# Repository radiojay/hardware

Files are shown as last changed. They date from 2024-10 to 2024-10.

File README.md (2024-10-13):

RadioJay Hardware Design
========================

This repo has various hardware designs for RadioJay wildlife tracking tags.
The first few were called "Mostag" for "Motus Open Source TAG" and then later rebranded to RadioJay.
The tags are listed here more or less in reverse chronological order.

For write-ups about these tags see the [RadioJay](https://radiojay.org) web site.

### RadioJay G1 - LoRaWAN+GPS tag

This is a collection of test & dev boards using a bit more space and with connectors to
attach probes and to swap between solar panels and GPS modules.

- [RadioJayG1-ublox](./RadioJayG1-ublox/) has a U-Blox Mia-M10Q GPS and an stm32wle5
  microcontroller with integrated LoRa radio.
- [RadioJayG1-lr1110](./RadioJayG1-lr1110/) has an LR1110 radio with snapshot GPS and with LoRa
  support and uses an stm32u083 microcontroller.
- [RadioJayG1-aem](./RadioJayG1-aem/) is a solar + battery module using an e-Peas AEM10330 energy
  harvesting chip with integrated buck converter; it can be used with a PowerFilm or an IXOLAR
  solar cell and with a LiPO or an LTO battery.
- [RadioJayG1-lr1110](./RadioJayG1-lr1110/) is a solar/battery module using an IXOLAR solar cell
  with an MPP volatge of 4.4V allowing direct charge without boost converter; it has a low Iq
  buck converter to output 1.8V

### RadioJay A2 / MostagV2

First real tag using FlexPCB with a target weight of 1g all-in (incl. loop harness).
Uses uC, Nichicon battery, PowerFilm solar, bq25504, and accelerometer
as well as altimeter (barometer)

RadioJay A2

#### RadioJay A2a / MostagV2a

Same board with layout changes to satisfy OSH Park's design rules.

### PgmAdapterV2

Adapter board for programming RadioJay A2MostagV2 using a simple USB-serial adapter chip.
Has connectors to attach various types of programming/debug probes.
Most likely not what "normal users" will use, but useful for development.

PgmAdapterV2

### RadioJay A1 / MostagV1

Initial proof of concept board, not for strapping to any animal, has uC,
Seiko battery, PowerFilm solar cell, bq25504, and accelerometer, plus linx antenna.

RadioJay A1

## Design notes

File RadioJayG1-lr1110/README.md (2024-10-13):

RadioJay G1 - LR1110
====================

Test & dev board for a Semtech LR1110, providing GPS snapshot functionality as well as LoRa radio.
A STM32U083 is used as microcontroller for its low power features, familiarity with its peripherals,
and its 256KB flash, which can be used to store GPS data.

The main purpose of the board is to prototype all the pieces and be able to measure power consumption.

Open questions that came up while designing the board:
- Is it possible to get away without 900Mhz RF switch, as one can with the stm32wle?
  The stm32wle datasheet has a footnote in the "sub-Ghz radio characteristics" stating
  "When not in RX operation mode up to 22 dBm is accepted [on RFI_P/RFI_N]". Neither the
  sx1262 nor the lr1110 datasheet have this note so it's not clear whether this is a feature added
  by ST when integrating the sx1262 or whether it's something Semtech doesn't feel the need to specify.
- Can the GPS LNA power be supplied by the LR1110, eliminating one awkward to route signal. The
  datasheet doesn't specify max source current but it does spec minimum V-high voltage @2.5mA,
  which is the typ consumption of the LNA (max is 3.5mA).
- What are the power consumption implications of having only one 32.768kHz xtal and routing the
  clock from the stm32u083 to the LR1110?
- Would rotating the stm32u883 improve the routing?
- What are the minimum RF test points needed in the "final" tag?

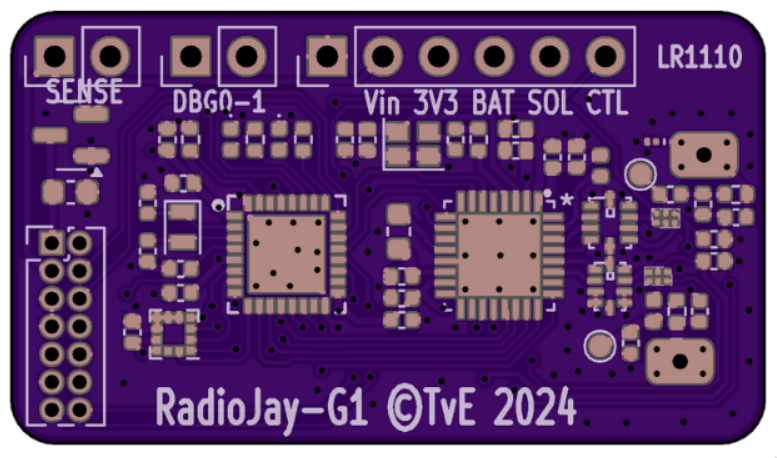
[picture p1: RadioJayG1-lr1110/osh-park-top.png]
Osh park board image


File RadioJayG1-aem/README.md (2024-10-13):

RadioJay G1
===========

Solar / battery module using a low-voltage solar cell (either IXOLAR or PowerFilm) with
E-Peas AEM10330 energy harvesting chip which has a buck converter to output 1.8V.

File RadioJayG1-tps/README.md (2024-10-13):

RadioJay G1
===========

Solar power test board using a solar panel with a MPP voltage around 4.4V allowing direct
charge of a LiPO battery without boost charger.
A high side power switch is used to end the charge and a switching power supply with extremely 
low Iq is used to output 1.8V.

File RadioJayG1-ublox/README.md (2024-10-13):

RadioJay G1
===========

Test & dev board for U-Blox Mia10Q GPS with stm32wle5 microcontroller and integrated LoRa radio.
This board needs to be powered at 1.8V due to the Mia-M10Q
(which could alternatively be powered at 3.3V).

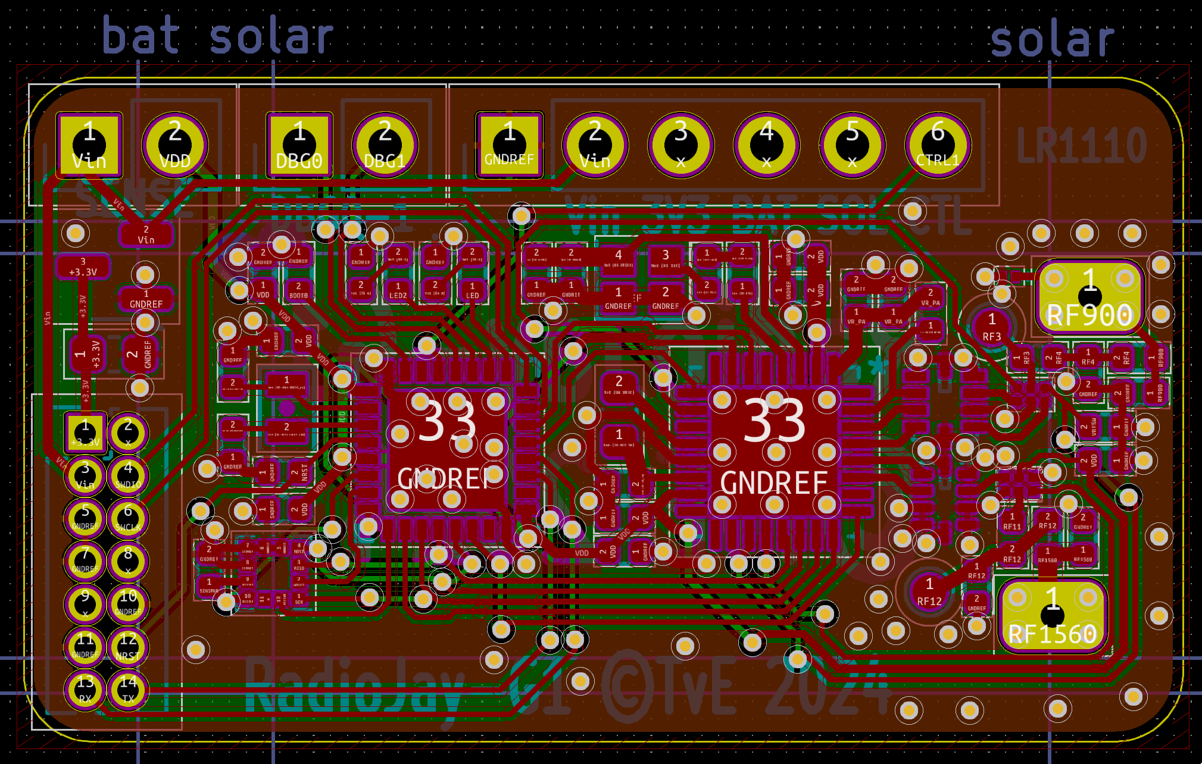
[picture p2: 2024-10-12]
RadioJayG1-lr1110/RadioJayG1-lr1110-pcb-front.png

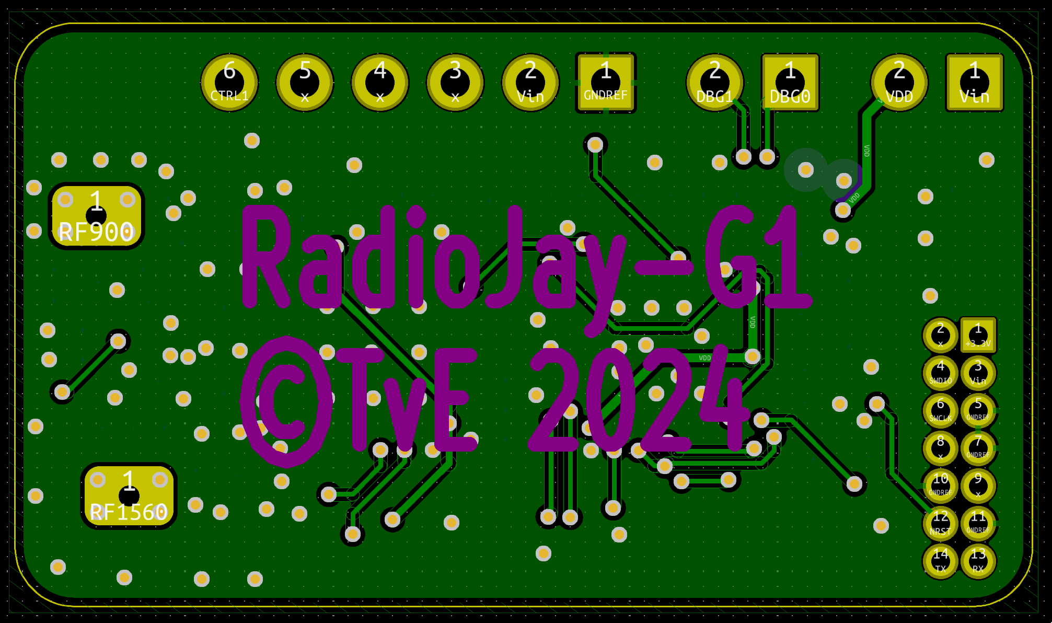
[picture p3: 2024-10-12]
RadioJayG1-lr1110/RadioJayG1-lr1110-pcb-back.png

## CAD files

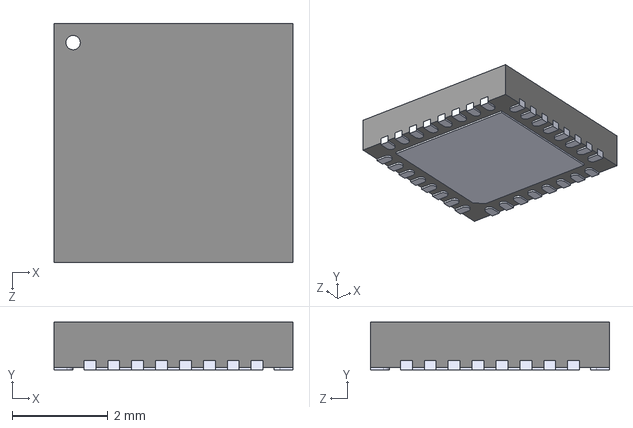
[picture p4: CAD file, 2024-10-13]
3d-models/LR1110IMLTRT.step
5.00 x 1.00 x 5.00 mm

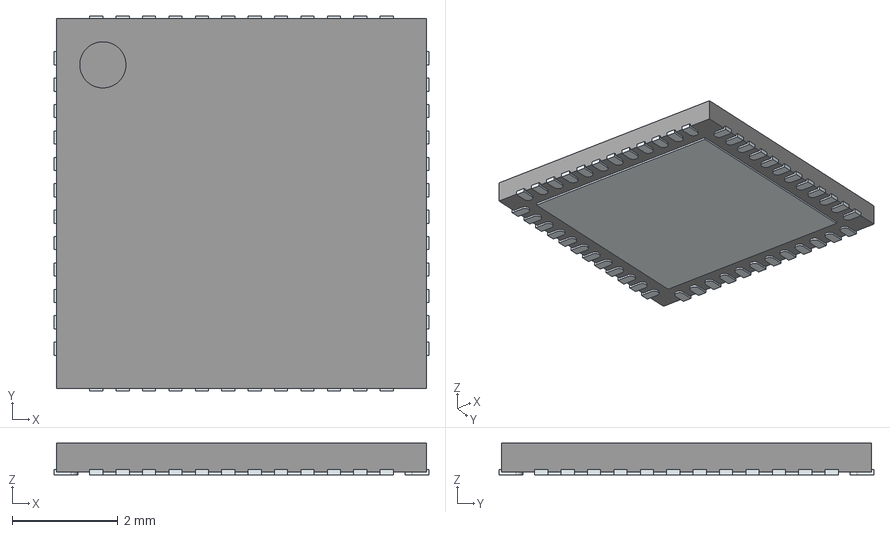
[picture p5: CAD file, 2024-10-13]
3d-models/STM32U083CCU6.stp
7.10 x 7.10 x 0.6 mm
ThermalPin
PinsArrayLR
PinsArrayTB

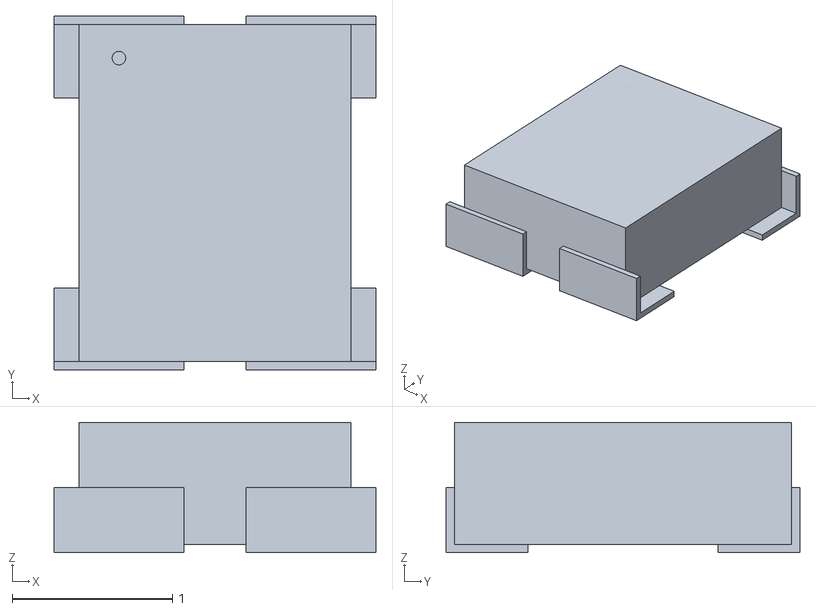
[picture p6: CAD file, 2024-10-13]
3d-models/NT2016SA-32M-END4263A_NDK.stl
2.01 x 2.21 x 0.815

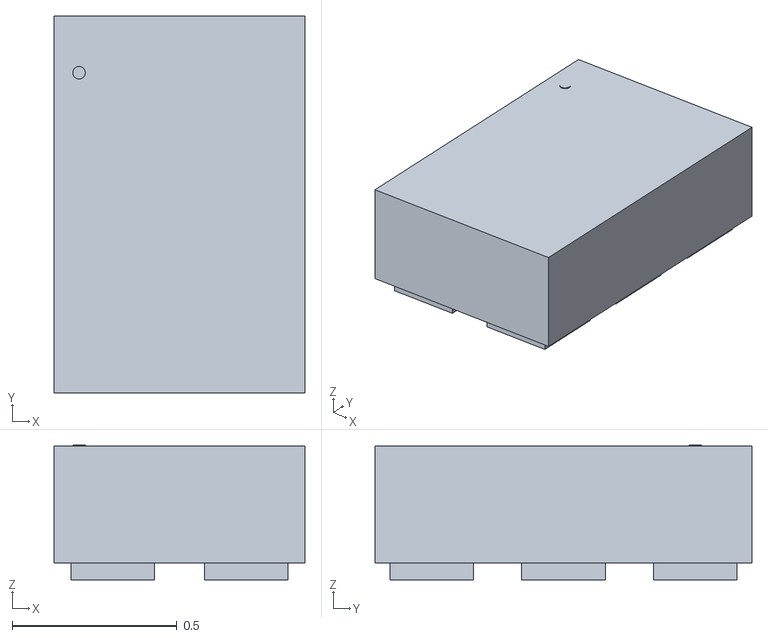
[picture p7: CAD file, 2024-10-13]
3d-models/PG-TSNP-6-2_INF.stl
0.762 x 1.14 x 0.409

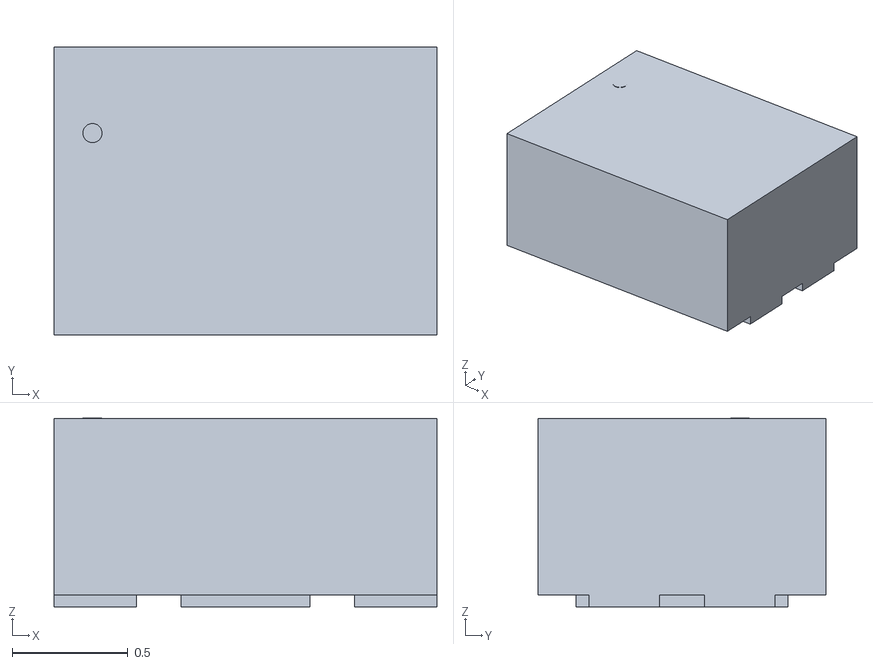
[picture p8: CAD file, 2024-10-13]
3d-models/DFN_NP3-T1GE4_VIS.stl
1.65 x 1.24 x 0.815

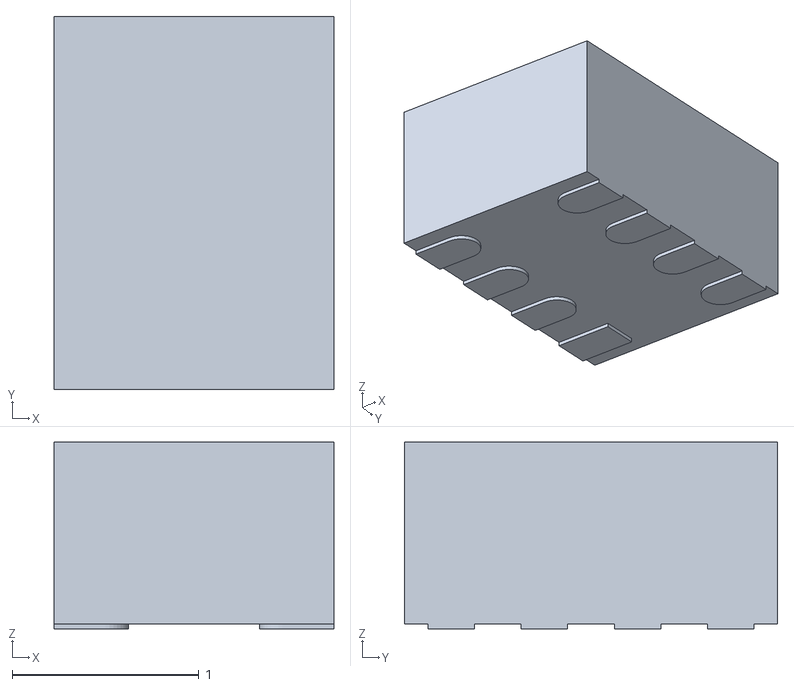
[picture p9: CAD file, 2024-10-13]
3d-models/DLC0008B.stl
1.50 x 2.00 x 1.00

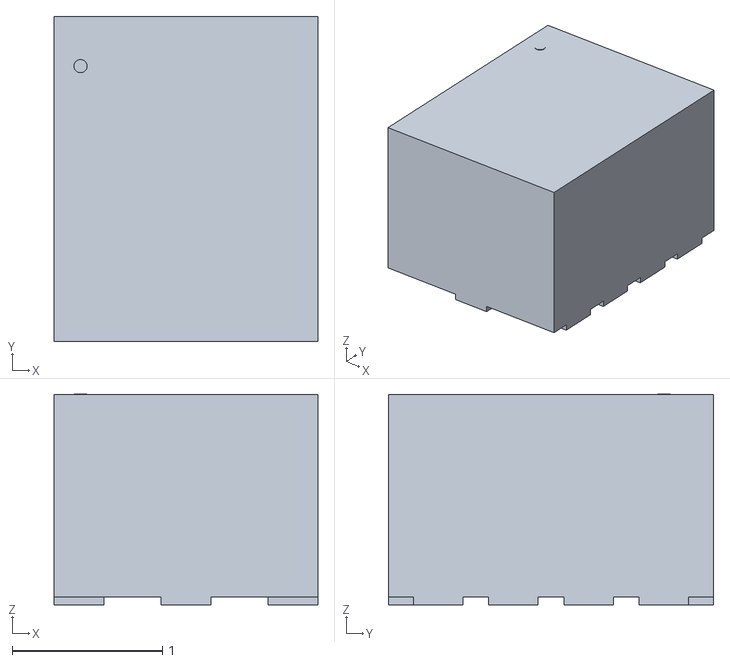
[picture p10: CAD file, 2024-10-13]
3d-models/CM80715_JOT.stl
1.75 x 2.16 x 1.40

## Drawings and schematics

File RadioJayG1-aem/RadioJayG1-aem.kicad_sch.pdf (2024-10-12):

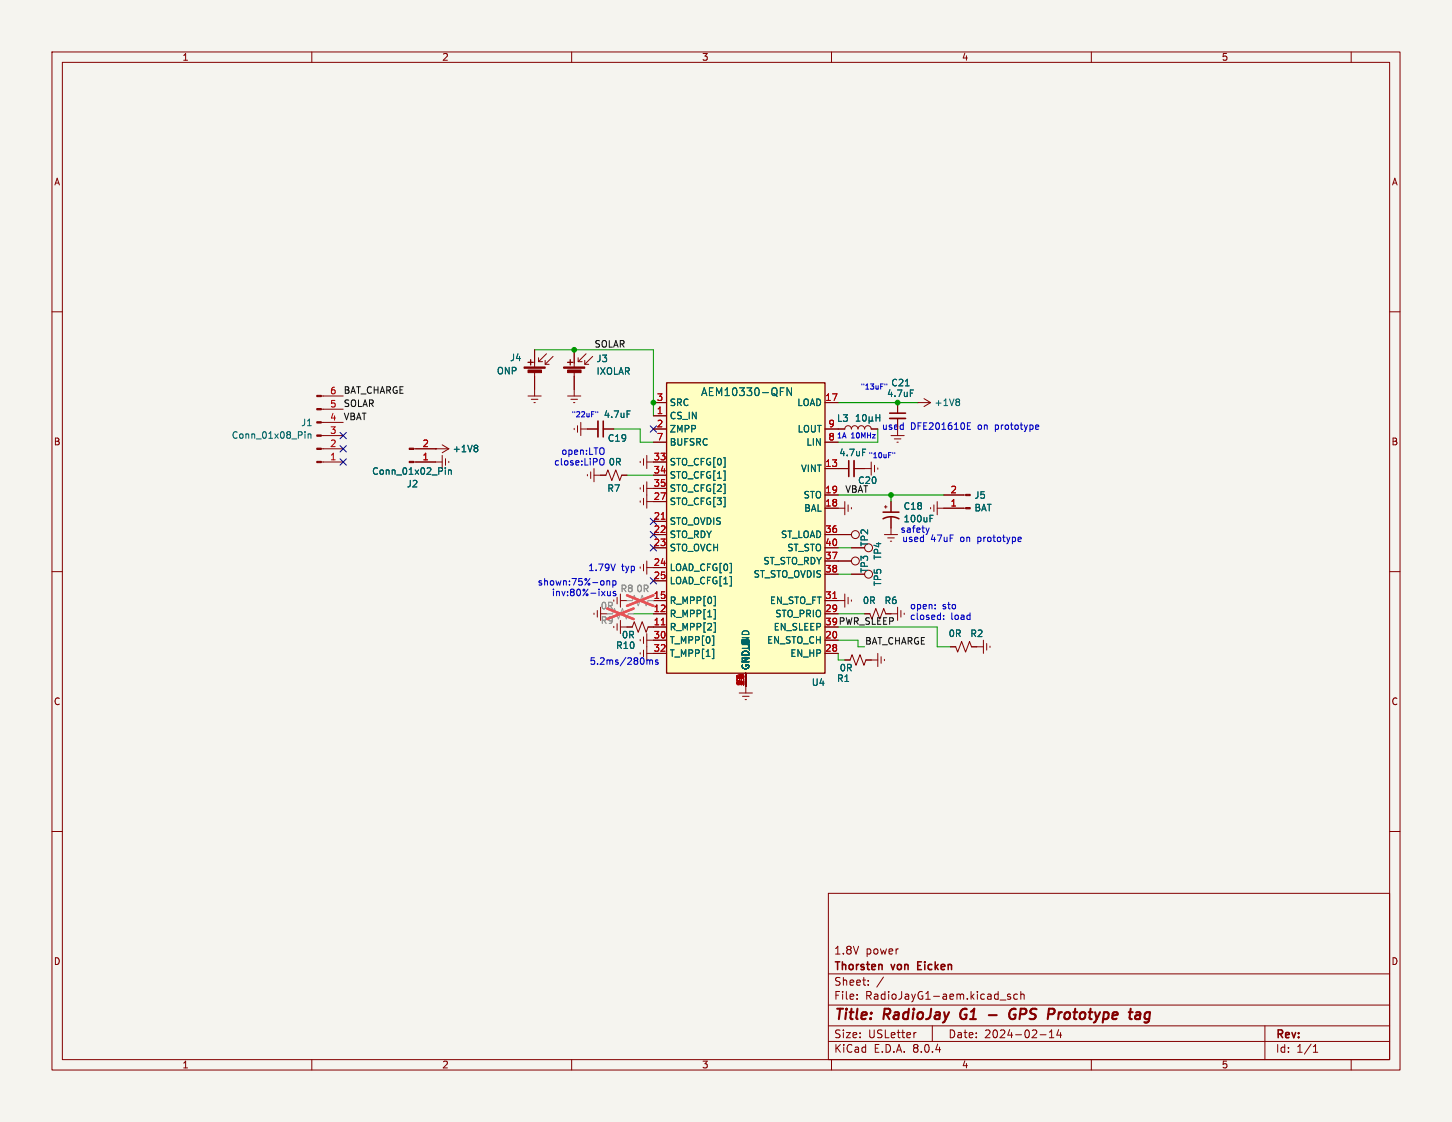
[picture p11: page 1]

Id: 1/1 Title: RadioJay G1 - GPS Prototype tag

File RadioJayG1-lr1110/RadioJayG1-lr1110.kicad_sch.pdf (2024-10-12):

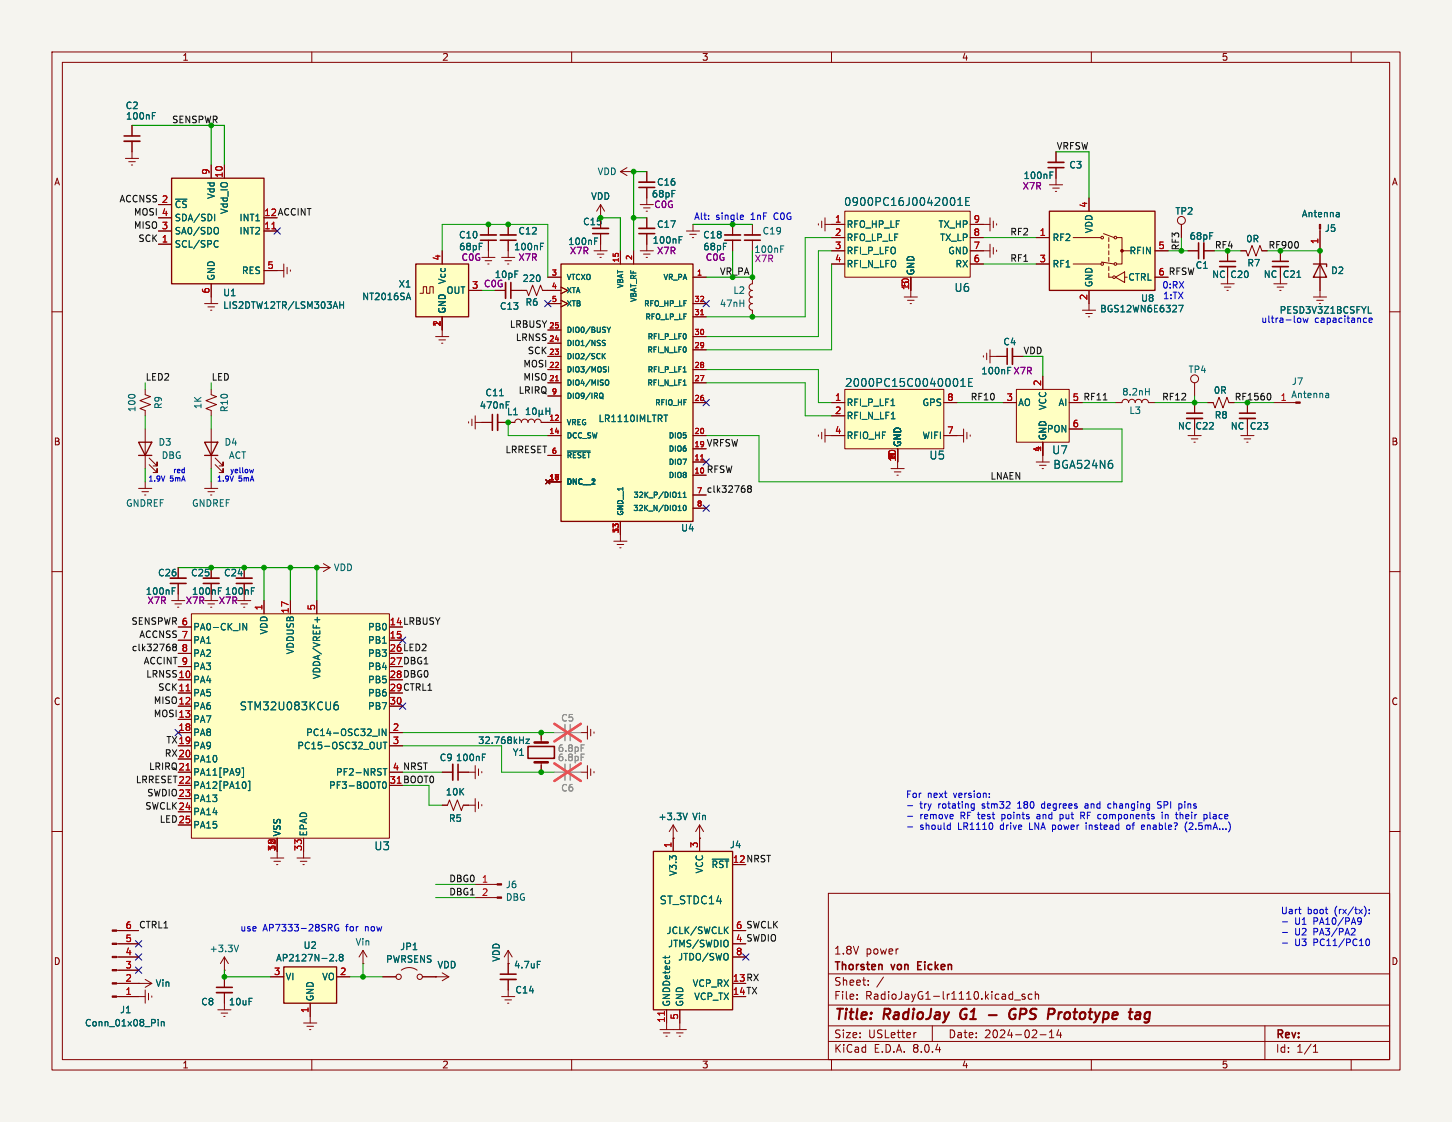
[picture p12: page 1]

12 OUT 3 Vcc 4 X1 NT2016SA RFO_HP_LF 1 GND 10 RFO_LP_LF 2 RFI_P_LFO 3 RFI_N_LFO 4 GND

2 DIO5 20 DIO0/BUSY 25 RFIO_HF 26 RFI_N_LF1 27 RFI_P_LF1 28 RFI_N_LF0 29 RFI_P_LF0 30 RFO_LP_LF 31 RFO_HP_LF 32 GND__1 33 XTA 4 XTB 5 ~{RESET} 6

1 PA4 10 PA5 11 PA6 12 PA7 13 PB0 14 PB1 15 VSS 16 VDDUSB 17 PA8 18 PA9 19 PC14-OSC32_IN 2 PA10 20 PA11[PA9] 21 PA12[PA10] 22 PA13 23 PA14 24 PA15 25 PB3 26 PB4 27 PB5 28 PB6 29 PC15-OSC32_OUT 3 PB7 30 PF3-BOOT0 31 VSS 32 EPAD 33 PF2-NRST 4 VDDA/VREF+

JTDO/SWO 8 +3.3V Vin U2 AP2127N-2.8 GND

- should LR1110 drive LNA power instead of enable? (2.5mA...)

Id: 1/1 Title: RadioJay G1 - GPS Prototype tag

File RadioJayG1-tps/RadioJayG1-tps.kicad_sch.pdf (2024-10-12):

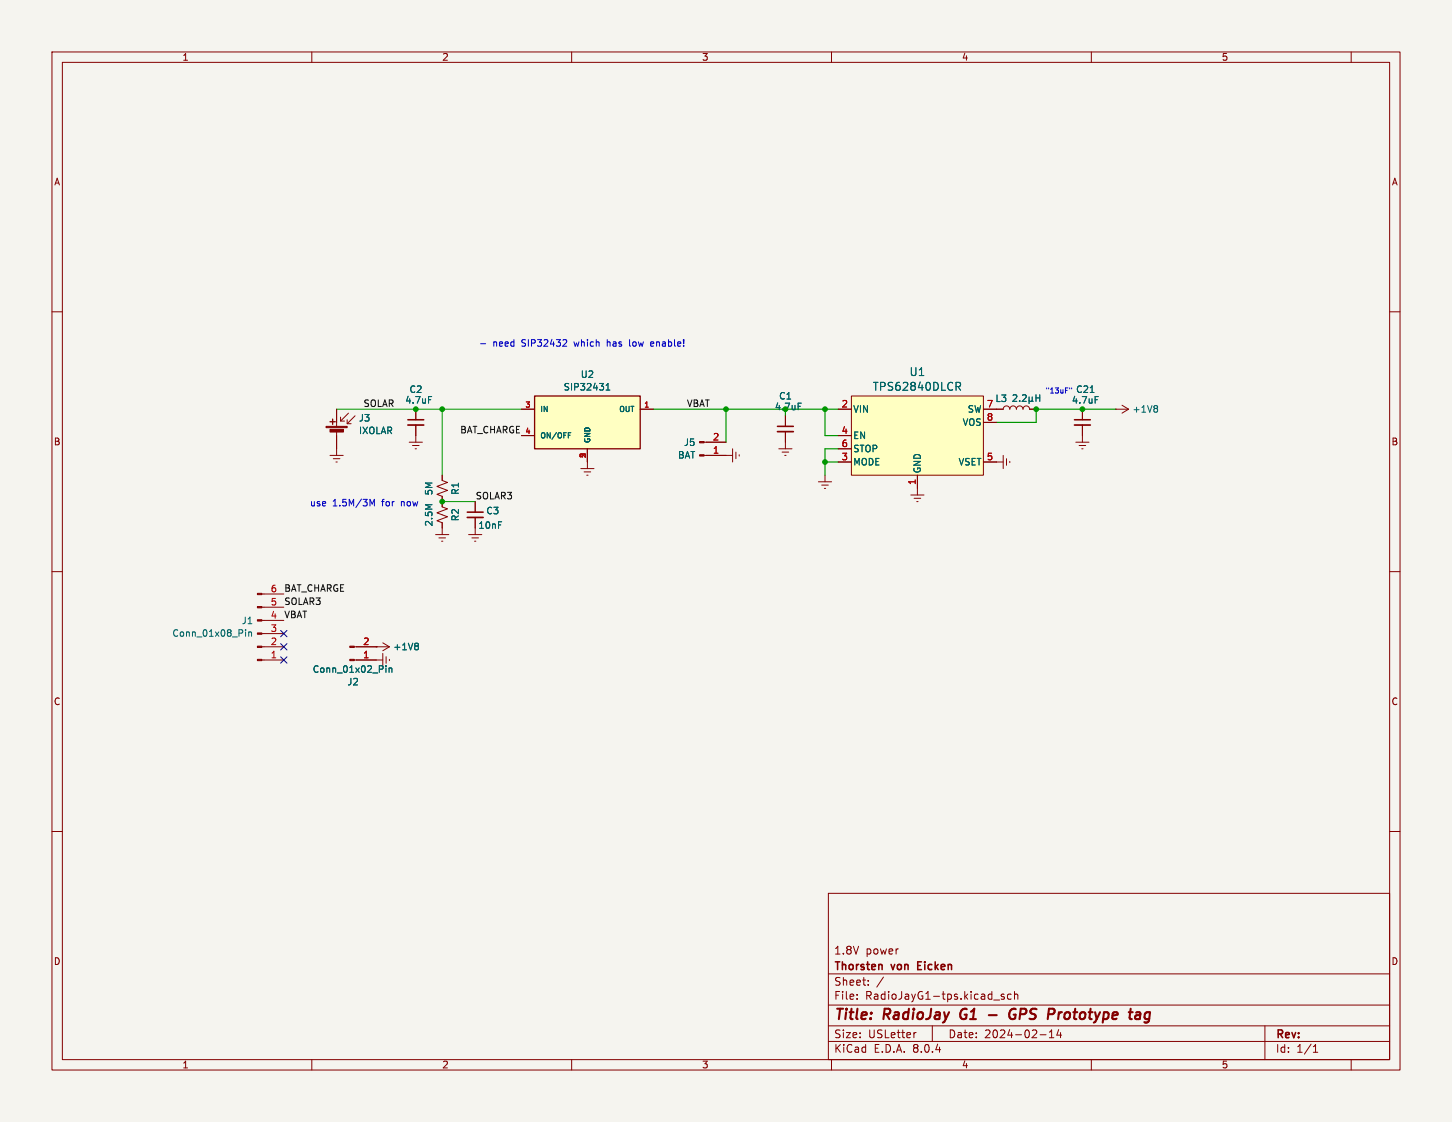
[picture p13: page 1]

1 VIN 2 MODE 3 EN 4 VSET 5 STOP 6 SW 7 VOS 8 U1 TPS62840DLCR

1 VIN 2 MODE 3 EN 4 VSET 5 STOP 6 SW 7 VOS 8

Id: 1/1 Title: RadioJay G1 - GPS Prototype tag

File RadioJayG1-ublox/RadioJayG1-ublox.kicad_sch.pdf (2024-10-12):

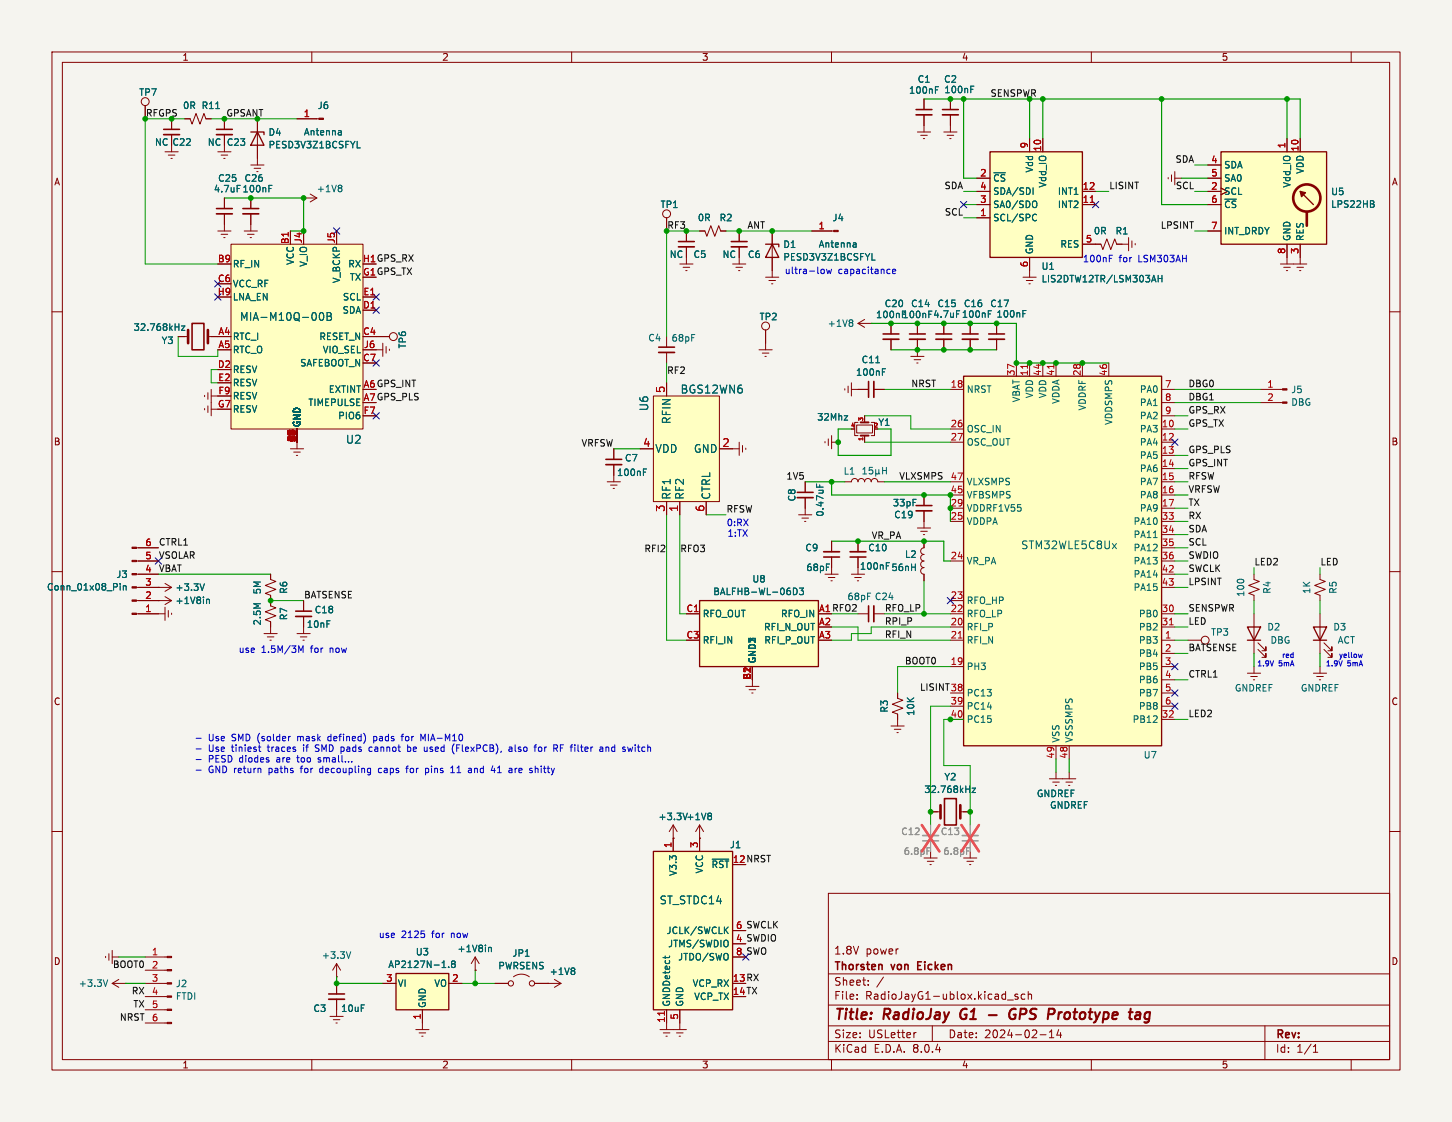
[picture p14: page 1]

Id: 1/1 Title: RadioJay G1 - GPS Prototype tag

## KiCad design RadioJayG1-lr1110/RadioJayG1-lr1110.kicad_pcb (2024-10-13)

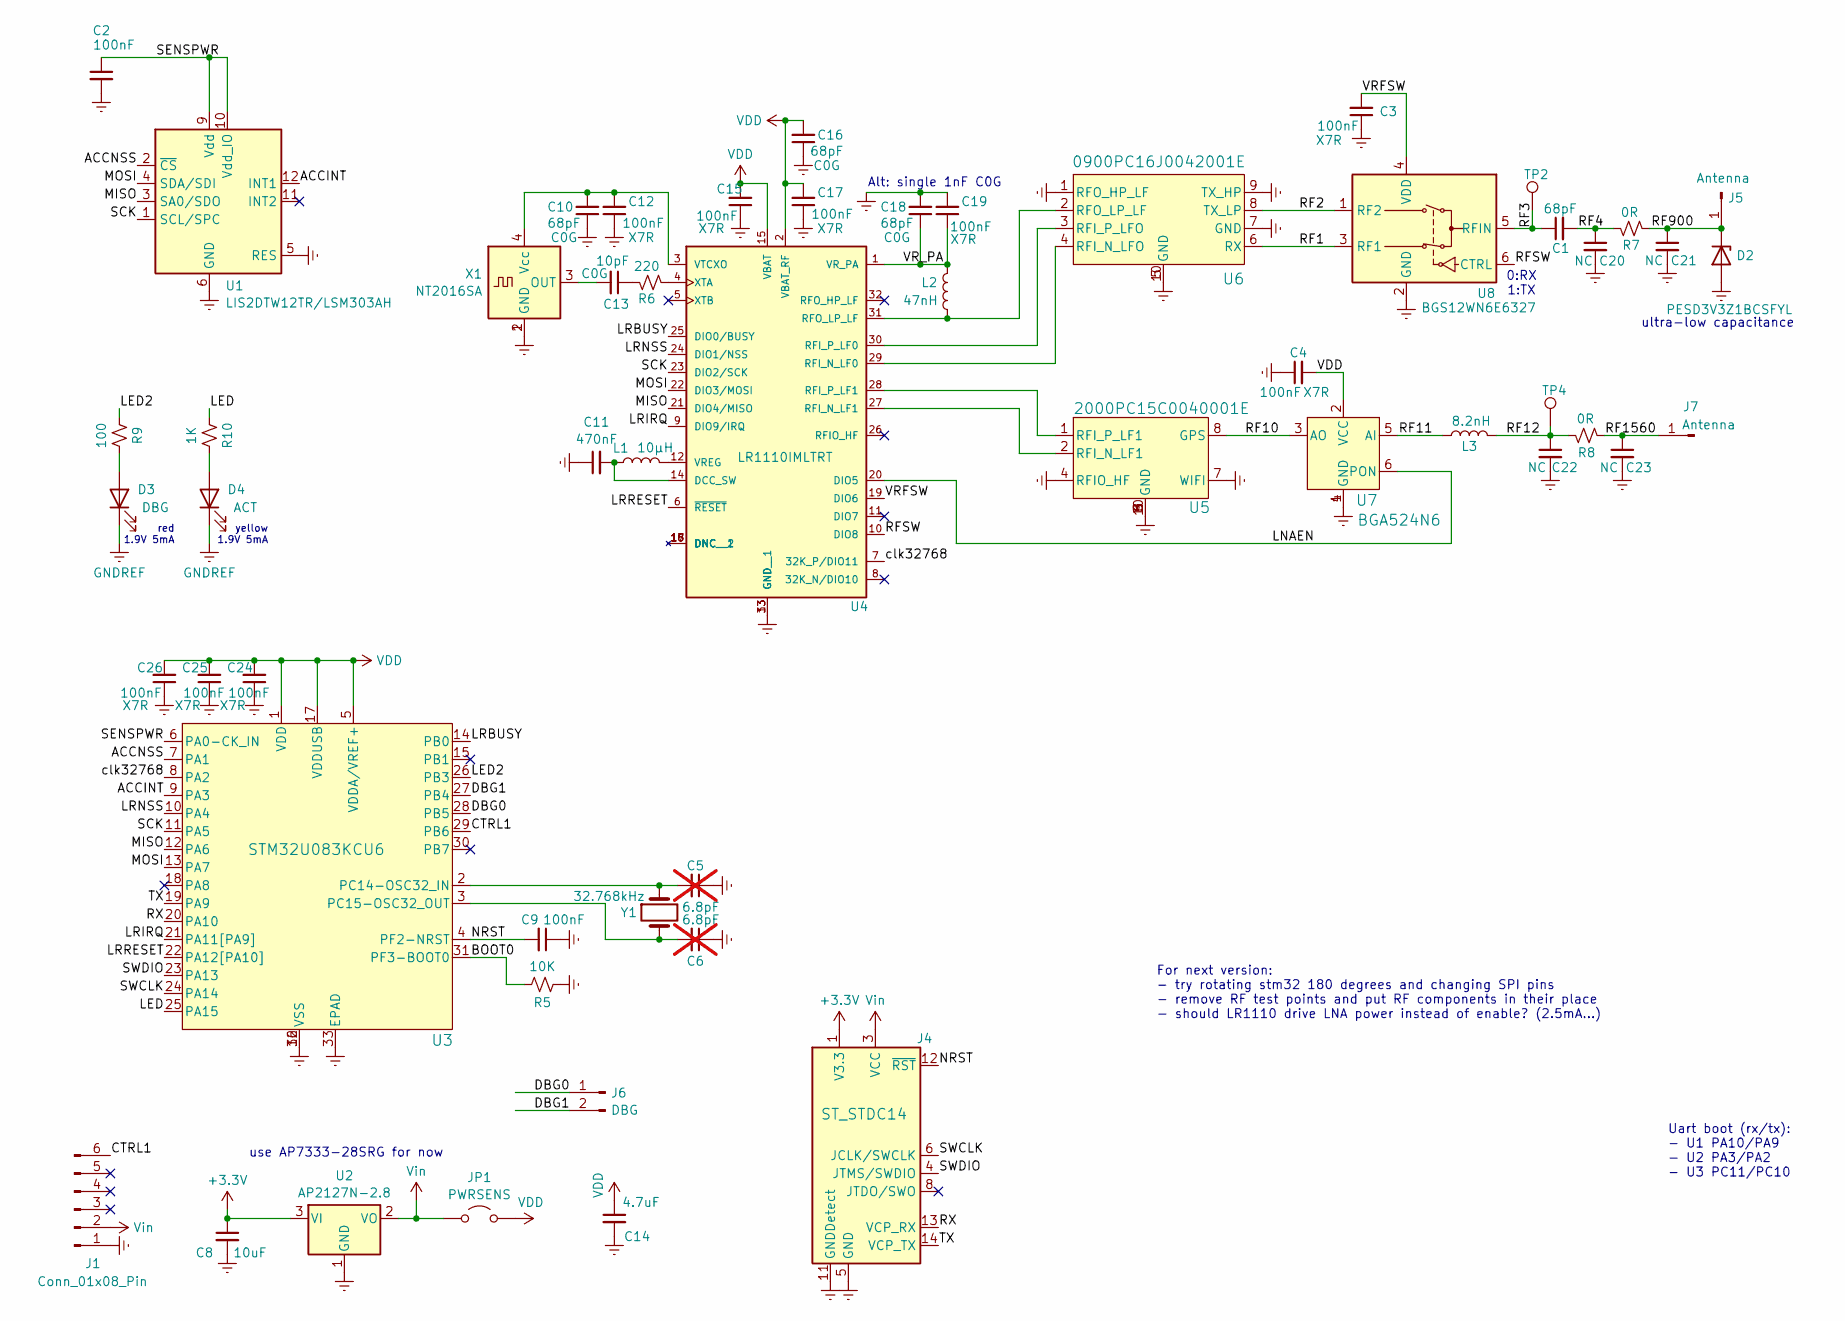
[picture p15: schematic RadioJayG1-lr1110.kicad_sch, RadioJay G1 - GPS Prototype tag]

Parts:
C1, C10, C16, C18: 68pF; C_0402_1005Metric
C2, C3, C4, C9, C12, C15, C17, C19, C24, C25, C26: 100nF; C_0402_1005Metric
C5, C6: 6.8pF; C_0402_1005Metric; not fitted
C8: 10uF; C_0603_1608Metric
C11: 470nF; C_0402_1005Metric
C13: 10pF; C_0402_1005Metric
C14: 4.7uF; C_0402_1005Metric
C20, C21, C22, C23: NC; C_0402_1005Metric
D2: PESD3V3Z1BCSFYL; Nexperia_DSN0603-2_0.6x0.3mm_P0.4mm
D3: DBG; LED_0402_1005Metric
D4: ACT; LED_0402_1005Metric
J1: Conn_01x08_Pin; PinHeader_1x06_P2.54mm_Vertical
J4: ST_STDC14; PinHeader_2x07_P1.27mm_Vertical
J5, J7: Antenna; ANT_PAD_2sided_3x2mm
J6: DBG; PinHeader_1x02_P2.54mm_Vertical
JP1: PWRSENS; PinHeader_1x02_P2.54mm_Vertical
L1: 10µH; L_0603_1608Metric; Part MLZ1608N100LT
L2: 47nH; L_0402_1005Metric; Part LQW15AN56NG00
L3: 8.2nH; L_0402_1005Metric; Part LQW
R5: 10K; R_0402_1005Metric
R6: 220; R_0402_1005Metric
R7, R8: 0R; R_0402_1005Metric
R9: 100; R_0402_1005Metric
R10: 1K; R_0402_1005Metric
TP2, TP4: TestPoint; TestPoint_Pad_D1.0mm
U1: LIS2DTW12TR/LSM303AH; LGA-12_2x2mm_P0.5mm
U2: AP2127N-2.8; SOT-23
U3: STM32U083KCU6; UFQFPN-32_STM
U4: LR1110IMLTRT; QFN50P500X500X100-33N; PARTREV 1.3
U5: 2000PC15C0040001E; Johanson-2000PC15
U6: 0900PC16J0042001E; Johanson-0900PC16
U7: BGA524N6; PG-TSNP-6-2_INF
U8: BGS12WN6E6327; Infineon_PG-TSNP-6-10_0.7x1.1mm_0.7x1.1mm_P0.4mm
X1: NT2016SA; Crystal_SMD_2016-4Pin_2.0x1.6mm
Y1: 32.768kHz; Crystal_SMD_2012-2Pin_2.0x1.2mm

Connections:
+3.3V: C8.1, J4.1 (V3.3), U2.3 (VI)
/ACCINT: U1.12 (INT1), U3.9 (PA3)
/ACCNSS: U1.2 (~CS), U3.7 (PA1)
/BOOT0: R5.2, U3.31 (PF3-BOOT0)
/CTRL1: J1.6, U3.29 (PB6)
/DBG0: J6.1, U3.28 (PB5)
/DBG1: J6.2, U3.27 (PB4)
/LED: R10.1, U3.25 (PA15)
/LED2: R9.1, U3.26 (PB3)
/LNAEN: U4.20 (DIO5), U7.6 (PON)
/LRBUSY: U3.14 (PB0), U4.25 (DIO0/BUSY)
/LRIRQ: U3.21 (PA11[PA9]), U4.9 (DIO9/IRQ)
/LRNSS: U3.10 (PA4), U4.24 (DIO1/NSS)
/LRRESET: U3.22 (PA12[PA10]), U4.6 (~RESET)
/MISO: U1.3 (SA0/SDO), U3.12 (PA6), U4.21 (DIO4/MISO)
/MOSI: U1.4 (SDA/SDI), U3.13 (PA7), U4.22 (DIO3/MOSI)
/NRST: C9.2, J4.12 (~RST), U3.4 (PF2-NRST)
/RF1: U6.6 (RX), U8.3 (RF1)
/RF2: U6.8 (TX_LP), U8.1 (RF2)
/RF3: C1.1, TP2.1, U8.5 (RFIN)
/RF4: C1.2, C20.1, R7.2
/RF10: U5.8 (GPS), U7.3 (AO)
/RF11: L3.1, U7.5 (AI)
/RF12: C22.1, L3.2, R8.2, TP4.1
/RF900: C21.1, D2.1 (K), J5.1, R7.1
/RF1560: C23.1, J7.1, R8.1
/RFSW: U4.10 (DIO8), U8.6 (CTRL)
/RX: J4.13 (VCP_RX), U3.20 (PA10)
/SCK: U1.1 (SCL/SPC), U3.11 (PA5), U4.23 (DIO2/SCK)
/SENSPWR: C2.1, U1.9 (Vdd), U1.10 (Vdd_IO), U3.6 (PA0-CK_IN)
/SWCLK: J4.6 (JCLK/SWCLK), U3.24 (PA14)
/SWDIO: J4.4 (JTMS/SWDIO), U3.23 (PA13)
/TX: J4.14 (VCP_TX), U3.19 (PA9)
/VRFSW: C3.2, U4.19 (DIO6), U8.4 (VDD)
/VR_PA: C18.1, C19.1, L2.2, U4.1 (VR_PA)
/clk32768: U3.8 (PA2), U4.7 (32K_P/DIO11)
GNDREF: C2.2, C3.1, C4.1, C5.1, C6.1, C8.2, C9.1, C10.1, C11.1, C12.1, C14.2, C15.1, C16.1, C17.1, C18.2, C19.2, C20.2, C21.2, C22.2, C23.2, C24.1, C25.1, C26.1, D2.2 (A), D3.1 (K), D4.1 (K), J1.1, J4.5 (GND), J4.7 (GND), J4.10 (JTDI/NC), J4.11 (GNDDetect), R5.1, U1.5 (RES), U1.6 (GND), U1.7 (GND), U1.8 (GND), U2.1 (GND), U3.16 (VSS), U3.32 (VSS), U3.33 (EPAD), U4.13 (GND), U4.33 (GND__1), U5.3 (GND), U5.4 (RFIO_HF), U5.5 (GND), U5.6 (GND), U5.7 (WIFI), U5.9 (GND), U5.10 (GND), U6.1 (RFO_HP_LF), U6.5 (GND), U6.7 (GND), U6.9 (TX_HP), U6.10 (GND), U7.1 (GND), U7.4 (GND), U8.2 (GND), X1.1 (GND), X1.2 (GND)
unnamed: C13.1, R6.2
unnamed: D3.2 (A), R9.2
unnamed: D4.2 (A), R10.2
unnamed: C5.2, U3.2 (PC14-OSC32_IN), Y1.1
unnamed: C6.2, U3.3 (PC15-OSC32_OUT), Y1.2
unnamed: C11.2, L1.1, U4.14 (DCC_SW)
unnamed: U4.29 (RFI_N_LF0), U6.4 (RFI_N_LFO)
unnamed: U4.27 (RFI_N_LF1), U5.2 (RFI_N_LF1)
unnamed: U4.30 (RFI_P_LF0), U6.3 (RFI_P_LFO)
unnamed: U4.28 (RFI_P_LF1), U5.1 (RFI_P_LF1)
unnamed: L2.1, U4.31 (RFO_LP_LF), U6.2 (RFO_LP_LF)
unnamed: L1.2, U4.12 (VREG)
unnamed: C10.2, C12.2, U4.3 (VTCXO), X1.4 (Vcc)
unnamed: R6.1, U4.4 (XTA)
unnamed: C13.2, X1.3 (OUT)
VDD: C4.2, C14.1, C15.2, C16.2, C17.2, C24.2, C25.2, C26.2, JP1.2 (B), U3.1 (VDD), U3.5 (VDDA/VREF+), U3.17 (VDDUSB), U4.2 (VBAT_RF), U4.15 (VBAT), U7.2 (VCC)
Vin: J1.2, J4.3 (VCC), JP1.1 (A), U2.2 (VO)

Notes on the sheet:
0:RX 1:TX
use AP7333-28SRG for now
red 1.9V 5mA
yellow 1.9V 5mA
ultra-low capacitance
Uart boot (rx/tx): - U1 PA10/PA9 - U2 PA3/PA2 - U3 PC11/PC10
Alt: single 1nF C0G
For next version: - try rotating stm32 180 degrees and changing SPI pins - remove RF test points and put RF components in their place - should LR1110 drive LNA power instead of enable? (2.5mA...)

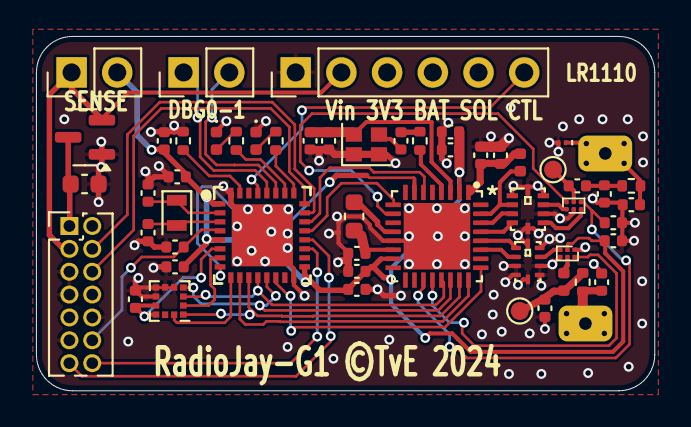
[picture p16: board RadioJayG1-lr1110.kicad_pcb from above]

Board: 2 copper layers, 34.4 x 19.7 mm, 55 parts (0 on the bottom side), 54 nets.

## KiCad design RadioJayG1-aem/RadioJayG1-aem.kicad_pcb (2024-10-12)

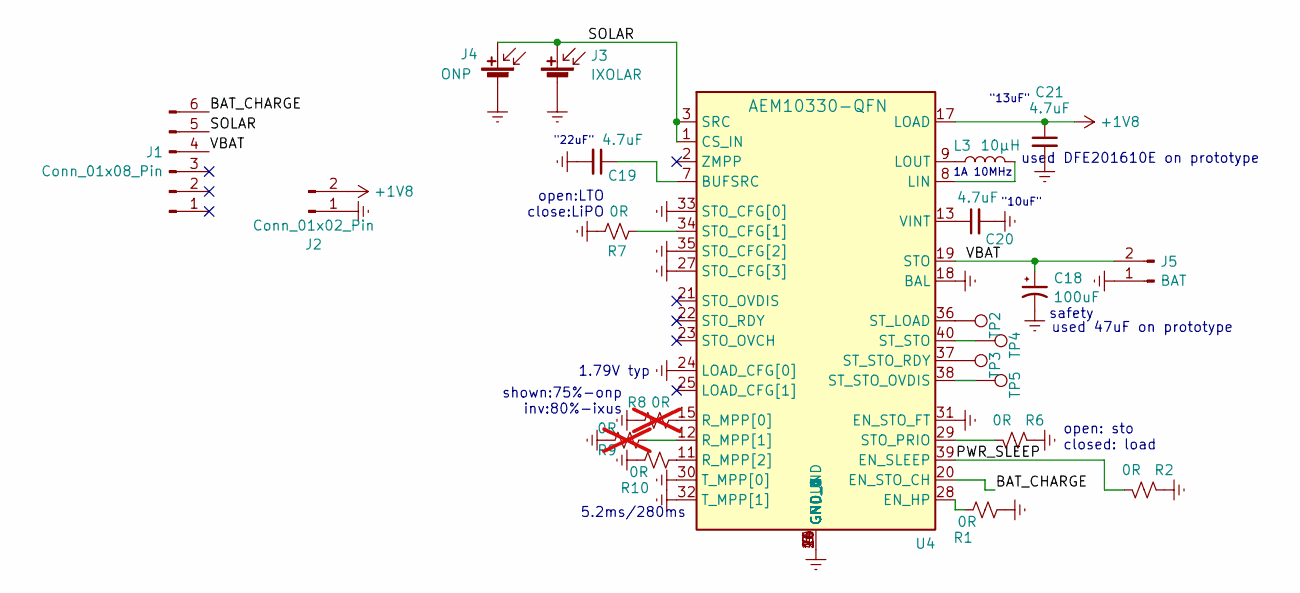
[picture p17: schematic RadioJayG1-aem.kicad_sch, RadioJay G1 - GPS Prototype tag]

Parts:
C18: 100uF; C_1206_3216Metric
C19, C20, C21: 4.7uF; C_0603_1608Metric
J1: Conn_01x08_Pin; PinHeader_1x06_P2.54mm_Vertical
J2: Conn_01x02_Pin; PinHeader_1x02_P2.54mm_Vertical
J3: IXOLAR; IXOLAR-23x8
J4: ONP; SOLAR_ONP1.2-cut-12x18
J5: BAT; LiPO-tabs-top-5mm
L3: 10µH; L_0805_2012Metric; Part MLZ2012M150W
R1, R2, R6, R7, R10: 0R; R_0402_1005Metric
R8, R9: 0R; R_0402_1005Metric; not fitted
TP2, TP3, TP4, TP5: TestPoint; TestPoint_Pad_D1.0mm
U4: AEM10330-QFN; QFN40P500X500X85-41N-D; Mouser Part Number 120-AEM10330-QFN

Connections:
+1V8: C21.1, J2.2, U4.17 (LOAD)
/BAT_CHARGE: J1.6, U4.20 (EN_STO_CH)
/PWR_SLEEP: R2.2, U4.39 (EN_SLEEP)
/SOLAR: J1.5, J3.1 (+), J4.1 (+), U4.1 (CS_IN), U4.3 (SRC)
/VBAT: C18.1, J1.4, J5.2, U4.19 (STO)
GNDREF: C18.2, C19.2, C20.2, C21.2, J2.1, J3.2 (-), J4.2 (-), J5.1, R1.2, R2.1, R6.1, R7.1, R8.1, R9.1, R10.1, U4.4 (GND_1), U4.5 (GND_2), U4.6 (GND_3), U4.10 (GND_4), U4.14 (GND_5), U4.16 (GND_6), U4.18 (BAL), U4.24 (LOAD_CFG[0]), U4.26 (GND_7), U4.27 (STO_CFG[3]), U4.30 (T_MPP[0]), U4.31 (EN_STO_FT), U4.32 (T_MPP[1]), U4.33 (STO_CFG[0]), U4.35 (STO_CFG[2]), U4.41 (GROUND)
unnamed: C19.1, U4.7 (BUFSRC)
unnamed: R1.1, U4.28 (EN_HP)
unnamed: L3.2, U4.8 (LIN)
unnamed: L3.1, U4.9 (LOUT)
unnamed: R8.2, U4.15 (R_MPP[0])
unnamed: R9.2, U4.12 (R_MPP[1])
unnamed: R10.2, U4.11 (R_MPP[2])
unnamed: R7.2, U4.34 (STO_CFG[1])
unnamed: R6.2, U4.29 (STO_PRIO)
unnamed: TP2.1, U4.36 (ST_LOAD)
unnamed: TP4.1, U4.40 (ST_STO)
unnamed: TP5.1, U4.38 (ST_STO_OVDIS)
unnamed: TP3.1, U4.37 (ST_STO_RDY)
unnamed: C20.1, U4.13 (VINT)

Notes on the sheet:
"13uF"
5.2ms/280ms
1A 10MHz
shown:75%-onp inv:80%-ixus
safety
used 47uF on prototype
"22uF"
open:LTO close:LiPO
used DFE201610E on prototype
1.79V typ
open: sto closed: load
"10uF"

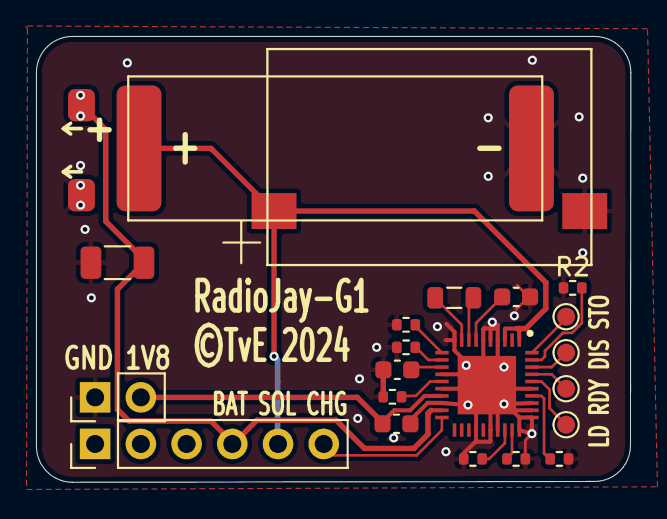
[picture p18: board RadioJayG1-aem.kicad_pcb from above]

Board: 2 copper layers, 33.0 x 24.8 mm, 22 parts (0 on the bottom side), 20 nets.

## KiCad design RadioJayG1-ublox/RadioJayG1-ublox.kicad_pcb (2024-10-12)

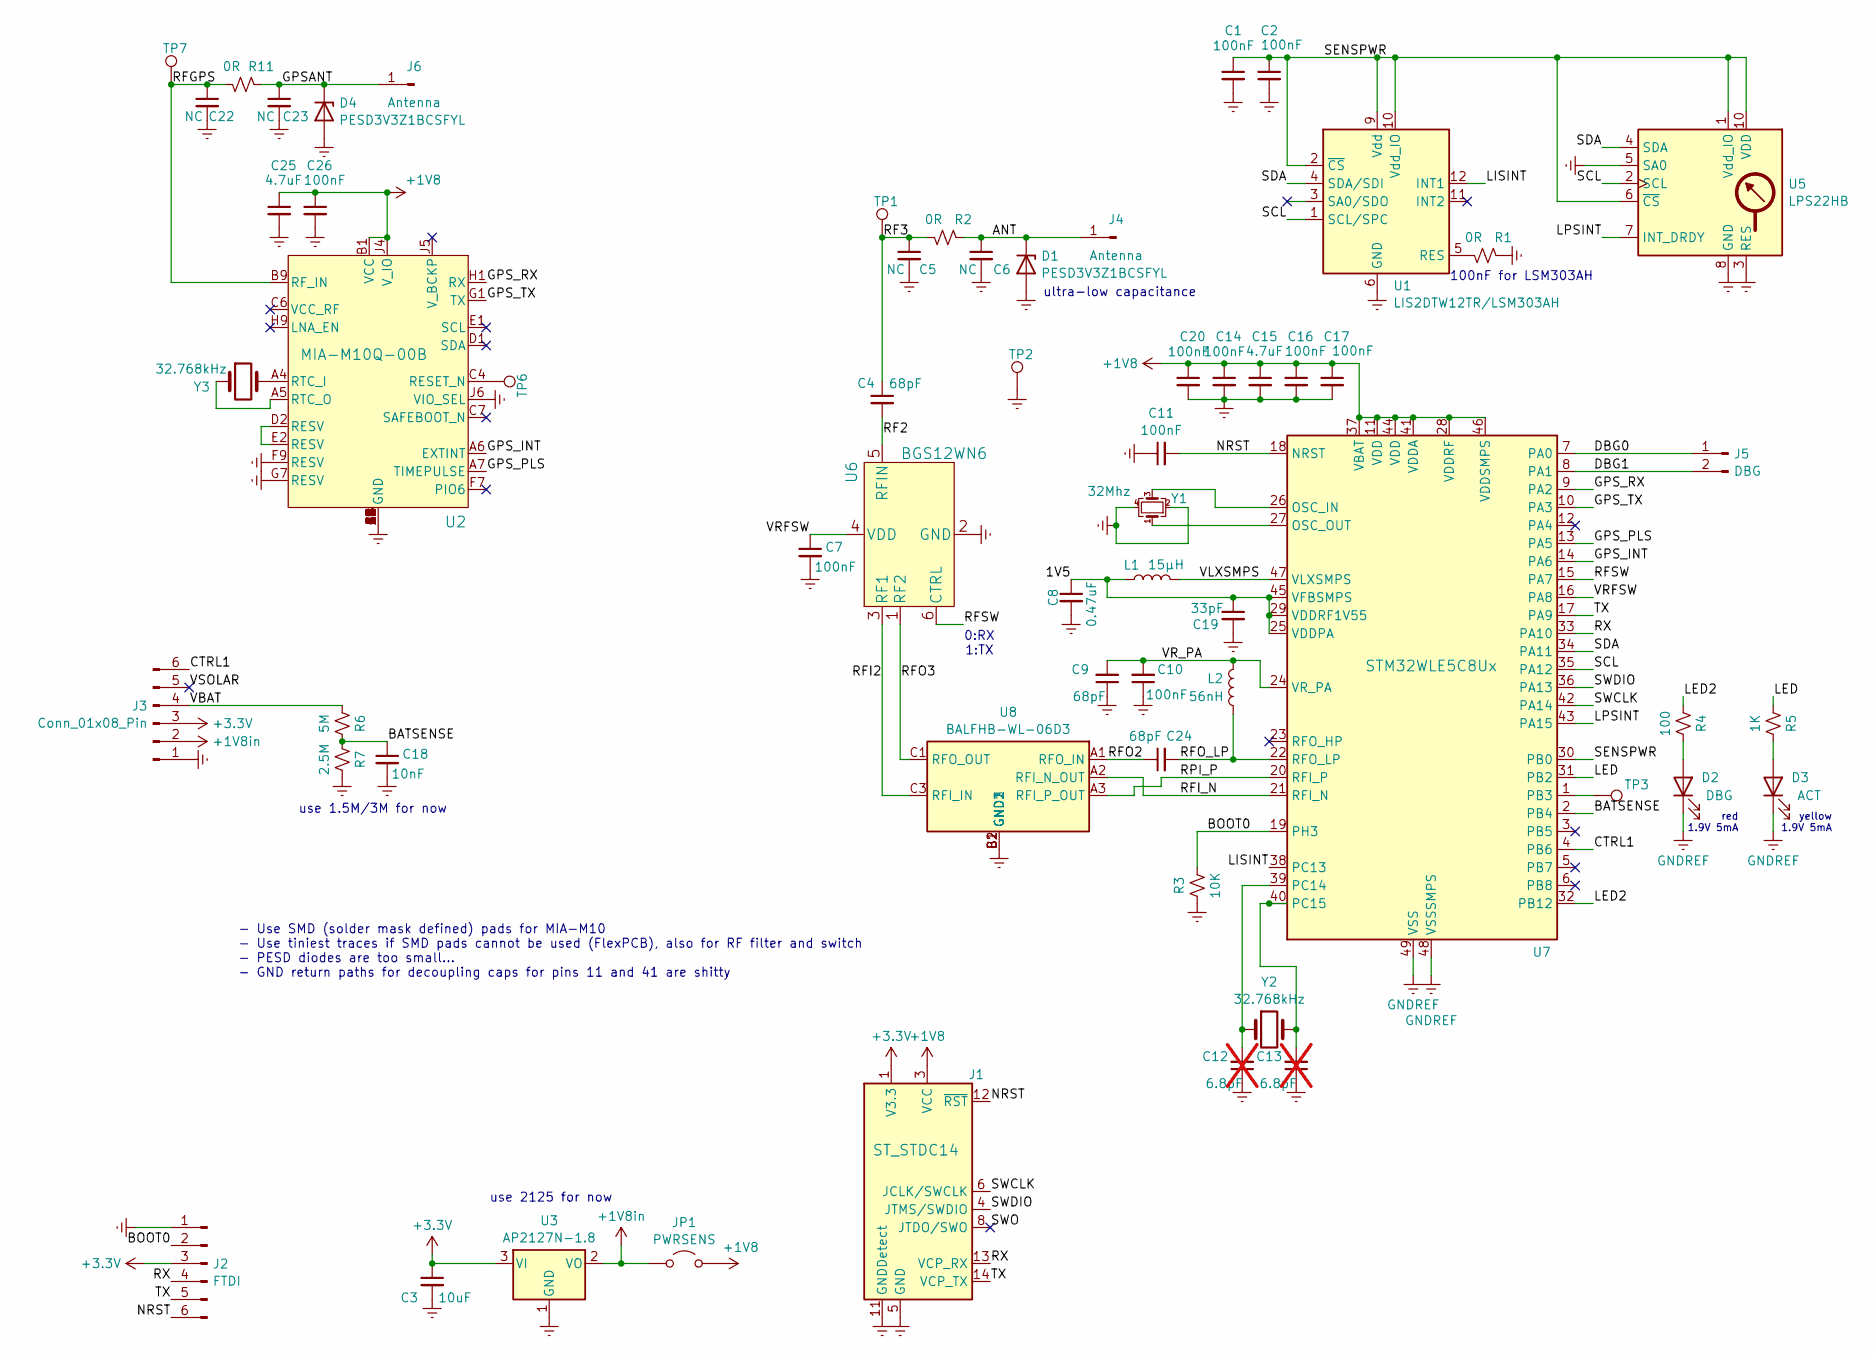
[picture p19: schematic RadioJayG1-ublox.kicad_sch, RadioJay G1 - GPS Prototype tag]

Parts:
C1, C2, C7, C10, C11, C14, C16, C17, C20, C26: 100nF; C_0402_1005Metric
C3: 10uF; C_0603_1608Metric
C4, C9, C24: 68pF; C_0402_1005Metric
C5, C6, C22, C23: NC; C_0402_1005Metric
C8: 0.47uF; C_0402_1005Metric
C12, C13: 6.8pF; C_0402_1005Metric; not fitted
C15, C25: 4.7uF; C_0402_1005Metric
C18: 10nF; C_0402_1005Metric
C19: 33pF; C_0402_1005Metric
D1, D4: PESD3V3Z1BCSFYL; Nexperia_DSN0603-2_0.6x0.3mm_P0.4mm
D2: DBG; LED_0402_1005Metric
D3: ACT; LED_0402_1005Metric
J1: ST_STDC14; PinHeader_2x07_P1.27mm_Vertical
J2: FTDI; PinHeader_1x06_P2.54mm_Vertical
J3: Conn_01x08_Pin; PinHeader_1x06_P2.54mm_Vertical
J4, J6: Antenna; ANT_PAD_2sided_3x2mm
J5: DBG; PinHeader_1x02_P2.54mm_Vertical
JP1: PWRSENS; PinHeader_1x02_P2.54mm_Vertical
L1: 15µH; L_0805_2012Metric; Part MLZ2012M150W
L2: 56nH; L_0402_1005Metric; Part LQW15AN56NG00
R1, R2, R11: 0R; R_0402_1005Metric
R3: 10K; R_0402_1005Metric
R4: 100; R_0402_1005Metric
R5: 1K; R_0402_1005Metric
R6: 5M; R_0402_1005Metric
R7: 2.5M; R_0402_1005Metric
TP1, TP2, TP6, TP7: TestPoint; TestPoint_Pad_D1.0mm
TP3: TestPoint; TestPoint_Pad_1.0x0.5mm
U1: LIS2DTW12TR/LSM303AH; LGA-12_2x2mm_P0.5mm
U2: MIA-M10Q-00B; LGA_M10Q-00B_UBL
U3: AP2127N-1.8; SOT-23
U5: LPS22HB; HLGA-10L_2X2X0P73_STM
U6: BGS12WN6; PG-TSNP-6-10_INF
U7: STM32WLE5C8Ux; QFN-48-1EP_7x7mm_P0.5mm_EP5.6x5.6mm
U8: BALFHB-WL-06D3; BALFHBWL06D3; Mouser Part Number 511-BALFHB-WL-06D3
Y1: 32Mhz; Crystal_SMD_2016-4Pin_2.0x1.6mm; Part NX2016SA-32Mhz (CS06465-32M)
Y2, Y3: 32.768kHz; Crystal_SMD_2012-2Pin_2.0x1.2mm

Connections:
+1V8: C14.1, C15.1, C16.1, C17.1, C20.1, C25.1, C26.1, J1.3 (VCC), JP1.2 (B), U2.B1 (VCC), U2.J4 (V_IO), U7.11 (VDD), U7.28 (VDDRF), U7.37 (VBAT), U7.41 (VDDA), U7.44 (VDD), U7.46 (VDDSMPS)
+1V8in: J3.2, JP1.1 (A), U3.2 (VO)
+3.3V: C3.1, J1.1 (V3.3), J2.3, J3.3, U3.3 (VI)
/1V5: C8.1, C19.1, L1.1, U7.25 (VDDPA), U7.29 (VDDRF1V55), U7.45 (VFBSMPS)
/ANT: C6.1, D1.1 (K), J4.1, R2.1
/BATSENSE: C18.1, R6.2, R7.1, U7.2 (PB4)
/BOOT0: J2.2, R3.2, U7.19 (PH3)
/CTRL1: J3.6, U7.4 (PB6)
/DBG0: J5.1, U7.7 (PA0)
/DBG1: J5.2, U7.8 (PA1)
/GPSANT: C23.1, D4.1 (K), J6.1, R11.1
/GPS_INT: U2.A6 (EXTINT), U7.14 (PA6)
/GPS_PLS: U2.A7 (TIMEPULSE), U7.13 (PA5)
/GPS_RX: U2.H1 (RX), U7.9 (PA2)
/GPS_TX: U2.G1 (TX), U7.10 (PA3)
/LED: R5.1, U7.31 (PB2)
/LED2: R4.1, U7.32 (PB12)
/LISINT: U1.12 (INT1), U7.38 (PC13)
/LPSINT: U5.7 (INT_DRDY), U7.43 (PA15)
/NRST: C11.2, J1.12 (~RST), J2.6, U7.18 (NRST)
/RF2: C4.2, U6.5 (RFIN)
/RF3: C4.1, C5.1, R2.2, TP1.1
/RFGPS: C22.1, R11.2, TP7.1, U2.B9 (RF_IN)
/RFI2: U6.3 (RF1), U8.C3 (RFI_IN)
/RFI_N: U7.21 (RFI_N), U8.A2 (RFI_N_OUT)
/RFO2: C24.1, U8.A1 (RFO_IN)
/RFO3: U6.1 (RF2), U8.C1 (RFO_OUT)
/RFO_LP: C24.2, L2.1, U7.22 (RFO_LP)
/RFSW: U6.6 (CTRL), U7.15 (PA7)
/RPI_P: U7.20 (RFI_P), U8.A3 (RFI_P_OUT)
/RX: J1.13 (VCP_RX), J2.4, U7.33 (PA10)
/SCL: U1.1 (SCL/SPC), U5.2 (SCL), U7.35 (PA12)
/SDA: U1.4 (SDA/SDI), U5.4 (SDA), U7.34 (PA11)
/SENSPWR: C1.1, C2.1, U1.2 (~CS), U1.9 (Vdd), U1.10 (Vdd_IO), U5.1 (Vdd_IO), U5.6 (~CS), U5.10 (VDD), U7.30 (PB0)
/SWCLK: J1.6 (JCLK/SWCLK), U7.42 (PA14)
/SWDIO: J1.4 (JTMS/SWDIO), U7.36 (PA13)
/SWO: J1.8 (JTDO/SWO)
/TX: J1.14 (VCP_TX), J2.5, U7.17 (PA9)
/VBAT: J3.4, R6.1
/VLXSMPS: L1.2, U7.47 (VLXSMPS)
/VRFSW: C7.1, U6.4 (VDD), U7.16 (PA8)
/VR_PA: C9.2, C10.2, L2.2, U7.24 (VR_PA)
/VSOLAR: J3.5
GNDREF: C1.2, C2.2, C3.2, C5.2, C6.2, C7.2, C8.2, C9.1, C10.1, C11.1, C12.1, C13.1, C14.2, C15.2, C16.2, C17.2, C18.2, C19.2, C20.2, C22.2, C23.2, C25.2, C26.2, D1.2 (A), D2.1 (K), D3.1 (K), D4.2 (A), J1.5 (GND), J1.7 (GND), J1.10 (JTDI/NC), J1.11 (GNDDetect), J2.1, J3.1, R1.1, R3.1, R7.2, TP2.1, U1.6 (GND), U1.7 (GND), U1.8 (GND), U2.A1 (GND), U2.A2 (GND), U2.A3 (GND), U2.A8 (GND), U2.A9 (GND), U2.B2 (GND), U2.B8 (GND), U2.C3 (GND), U2.C9 (GND), U2.E3 (GND), U2.E4 (GND), U2.E9 (GND), U2.F1 (GND), U2.F3 (GND), U2.F4 (GND), U2.F9 (RESV), U2.G3 (GND), U2.G4 (GND), U2.G5 (GND), U2.G6 (GND), U2.G7 (RESV), U2.H8 (GND), U2.J6 (VIO_SEL), U2.J8 (GND), U2.J9 (GND), U3.1 (GND), U5.3 (RES), U5.5 (SA0), U5.8 (GND), U5.9 (GND), U6.2 (GND), U7.48 (VSSSMPS), U7.49 (VSS), U8.B1 (GND2), U8.B2 (GND3), U8.C2 (GND1), Y1.2, Y1.4
unnamed: D2.2 (A), R4.2
unnamed: D3.2 (A), R5.2
unnamed: R1.2, U1.5 (RES)
unnamed: TP6.1, U2.C4 (RESET_N)
unnamed: U2.D2 (RESV), U2.E2 (RESV)
unnamed: U2.A4 (RTC_I), Y3.2
unnamed: U2.A5 (RTC_O), Y3.1
unnamed: U7.26 (OSC_IN), Y1.3
unnamed: U7.27 (OSC_OUT), Y1.1
unnamed: TP3.1, U7.1 (PB3)
unnamed: C12.2, U7.39 (PC14), Y2.1
unnamed: C13.2, U7.40 (PC15), Y2.2

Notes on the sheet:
- Use SMD (solder mask defined) pads for MIA-M10 - Use tiniest traces if SMD pads cannot be used (FlexPCB), also for RF filter and switch - PESD diodes are too small... - GND return paths for decoupling caps for pins 11 and 41 are shitty
use 2125 for now
use 1.5M/3M for now
red 1.9V 5mA
yellow 1.9V 5mA
ultra-low capacitance
0:RX 1:TX
100nF for LSM303AH

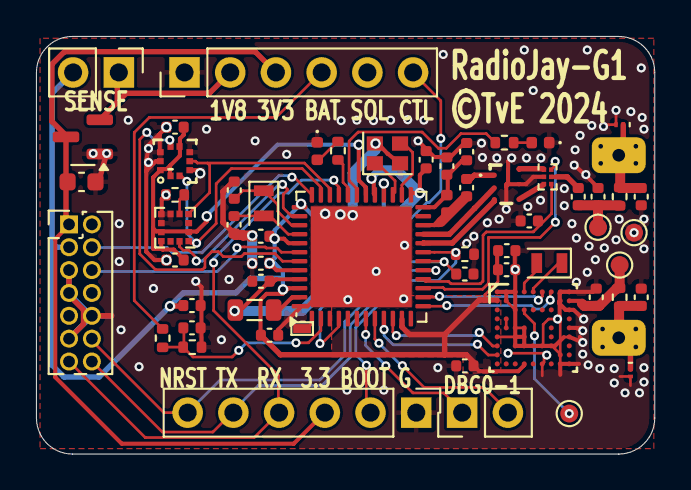
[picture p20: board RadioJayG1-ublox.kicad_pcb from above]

Board: 2 copper layers, 34.4 x 23.2 mm, 61 parts (0 on the bottom side), 54 nets.

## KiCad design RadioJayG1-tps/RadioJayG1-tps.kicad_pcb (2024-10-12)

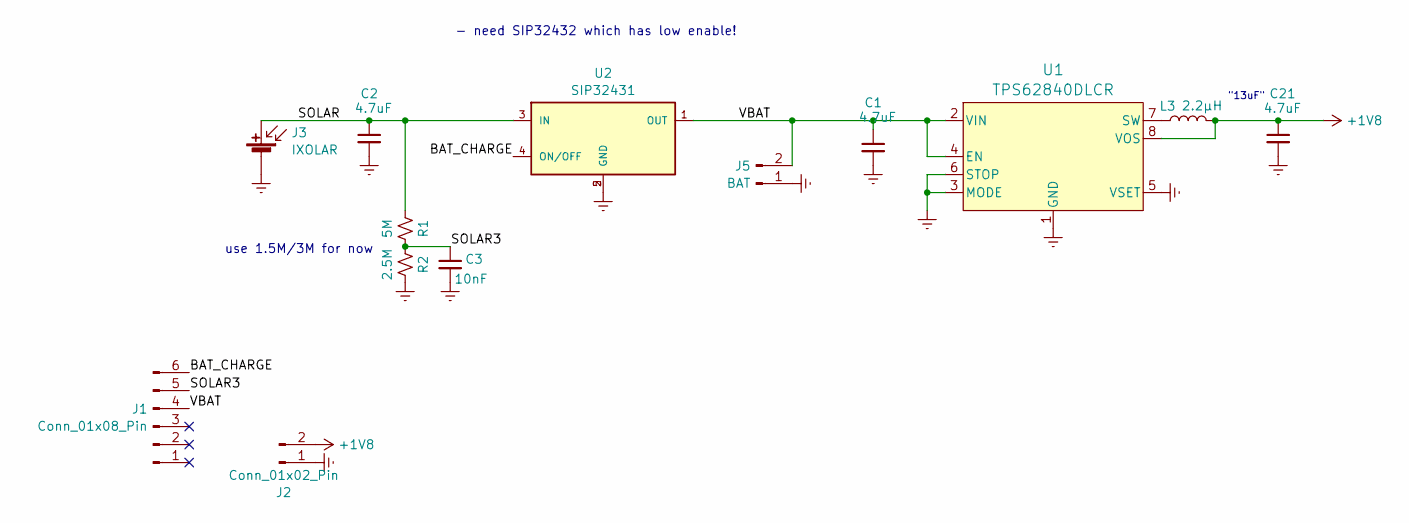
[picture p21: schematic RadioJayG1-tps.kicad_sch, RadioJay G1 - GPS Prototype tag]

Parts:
C1, C2, C21: 4.7uF; C_0603_1608Metric
C3: 10nF; C_0402_1005Metric
J1: Conn_01x08_Pin; PinHeader_1x06_P2.54mm_Vertical
J2: Conn_01x02_Pin; PinHeader_1x02_P2.54mm_Vertical
J3: IXOLAR; IXOLAR-23x8
J5: BAT; LiPO-tabs-top-5mm
L3: 2.2µH; L_0805_2012Metric; Part MLZ2012M150W
R1: 5M; R_0402_1005Metric
R2: 2.5M; R_0402_1005Metric
U1: TPS62840DLCR; VSON8_2P1X1P6_TEX
U2: SIP32431; DFN_NP3-T1GE4_VIS

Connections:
+1V8: C21.1, J2.2, L3.2, U1.8 (VOS)
/BAT_CHARGE: J1.6, U2.4 (ON/OFF)
/SOLAR: C2.1, J3.1 (+), R1.1, U2.3 (IN)
/SOLAR3: C3.1, J1.5, R1.2, R2.1
/VBAT: C1.1, J1.4, J5.2, U1.2 (VIN), U1.4 (EN), U2.1 (OUT)
GNDREF: C1.2, C2.2, C3.2, C21.2, J2.1, J3.2 (-), J5.1, R2.2, U1.1 (GND), U1.3 (MODE), U1.5 (VSET), U1.6 (STOP), U2.2 (GND), U2.5 (GND)
unnamed: L3.1, U1.7 (SW)

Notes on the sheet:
"13uF"
- need SIP32432 which has low enable!
use 1.5M/3M for now

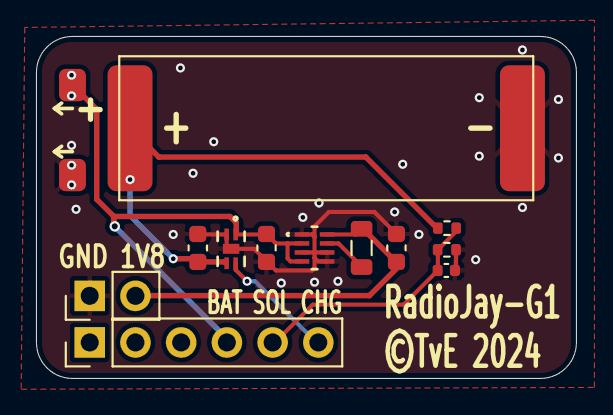
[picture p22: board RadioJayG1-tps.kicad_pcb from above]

Board: 2 copper layers, 30.0 x 19.0 mm, 13 parts (0 on the bottom side), 7 nets.

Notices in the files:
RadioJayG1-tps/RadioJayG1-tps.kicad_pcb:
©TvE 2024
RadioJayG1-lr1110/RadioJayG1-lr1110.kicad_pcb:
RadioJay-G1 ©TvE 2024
